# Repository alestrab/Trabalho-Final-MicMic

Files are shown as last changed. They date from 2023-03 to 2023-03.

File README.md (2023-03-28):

# Trabalho-Final-MicMic
Trabalho 7 da Disciplina de Microntroladores e Microprocessadores, Período 2022/2 - Engenharia Física - UFSCar;\
Grupo D, Professor da Disciplina: Dr. Ricardo Menotti
<div align="center">
 
Integrantes|RA
------|:----:
Alexandre Strabello|770076
Gabriel Lemes Molizane Almeida|770097
Sarah Brennda Bispo Almeida|770161

 <div align="left">
  
## Objetivos Gerais:
Girassol - Desenvolver um sistema para maximizar a intensidade luminosa em uma placa solar através da movimentação da mesma em dois eixos. 

### Objetivos Específicos:
Construir um suporte com um grau de liberdade em modelo 3D, com fácil adição de um segundo eixo de rotação;\
Desenvolvimento de um código para microcontrolador controlando dois servomotores em função da tensão de saída da placa solar;
 
## Materiais:

2 servomotores SG92R para controle dos eixos de rotação da placa solar; (por questão de disponibilidade foi utilizado um servomotor MG90S)

Mini Placa Solar ZW 110X69, tensão de operação 5 V, 1W;

Impressora 3D disponível no Espaço Maker do DC UFSCar;

Como microcontrolador foi utilizado um [Franzino](https://embarcados.com.br/franzino-open-hardware-de-baixo-custo/). O funcionamento do mesmo é o mesmo que um Arduino UNO, apenas necessita de uma placa externa para comunicação serial e não possui pinos de saída 3.3V.

## Plano de Trabalho

O projeto será separado com base nas quatro semanas disponíveis para sua realização;

### Primeira Semana:
Análise de viabilidade, quais componentes serão necessários, especificações sobre suas dimensões, assim como qual microcontrolador será utilizado;\
Também será construído uma primeira versão para controle de rotação em um único eixo em modelo 3D, onde será estudada a possibilidade de construção do mesmo em impressora 3D no laboratório maker do DC UFSCar;

### Segunda Semana:
Aperfeiçoamento do modelo e agendamento para impressão; \
Construção da segunda parte do modelo para controle no segundo eixo;\
Início do desenvolvimento do código para controle dos servomotores;

### Terceira Semana:
Impressão da segunda parte do suporte;\
Instalação e montagem do sistema da placa solar com os servomotores e demais componentes;\
Testes do código para controle e correções de bugs;

### Quarta Semana:
Correções de problemas;\
Elaboração de vídeo ou apresentação para a entrega final do projeto;

## Metodologia

Enquanto parte dos integrantes focam no desenvolvimento do suporte para fixação da placa e instalação dos servomotores, os outros membros serão responsáveis pela implementação do código para controle da rotação.

A inclinação da placa pode ser alterada em 45° para os dois lados, tal que será feito uma rotina para variar de 5° em 5° a inclinação enquanto faz a leitura da tensão na placa e verifica se houve redução ou não da mesma. Quando o movimento reduzir a intensidade luminosa, o mesmo irá parar de se movimentar nessa direção.

Em seguida, irá iniciar o movimento no segundo eixo, que pode rotacionar a placa em 360°, seguindo mesmo critério, movimentação em passo constante até identificar o pico de intensidade luminosa na placa.

## Realização do Plano de Trabalho

### Vídeo

O vídeo para apresentação do projeto Girassol e seu funcionamento está disponível no link: https://drive.google.com/file/d/1Eip5RgSgDWEnfYKRLRbnenWwQcjCiUuC/view?usp=share_link .

### Construção do modelo 3D

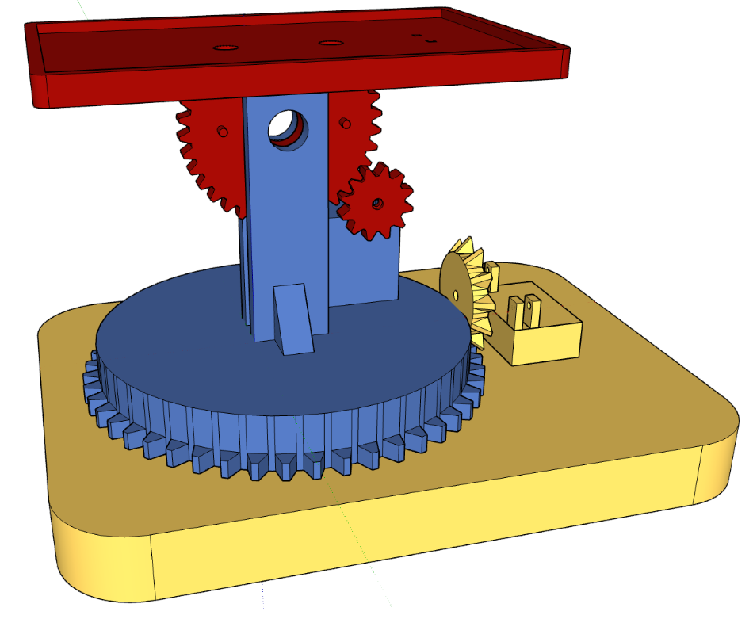
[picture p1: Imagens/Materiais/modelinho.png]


Utilizou-se o software Sketchup para construção dos suportes e sistemas para rotação da placa solar. O modelamento das engrenagens foi feito com base em objetos já existentes em um banco de projetos do aplicativo, enquanto o suporte foi pensado de acordo com alguns diagramas construidos inicialmente em papel. No total temos três grandes áreas, que seriam o controle de inclinação (em vermelho), o suporte para fixação da placa (em azul), além do suporte para o eixo de rotação (em amarelo).

Tanto o controle de inclinação quanto o suporte de fixação foram impressos em um laboratório do departamento de Física da universidade, contudo, por ordens dos responsáveis do local, não foi possível realizar a impressão do último componente. Verificou-se também que o eixo de rotação não poderia ser implementado utilizando um servomotor, tal como fora planejado.

O servomotor comprado apresenta limitação de rotação, podendo realizar no máximo um giro de 180°. Quando comparado com as engrenagens colocadas, a rotação máxima seria de 45°, muito inferior ao planejado de 360º. Como esse problema só foi identificado durante a implementação do controle de inclinação, não houve tempo para alteração do modelo, de modo que foi deixado de lado o controle de rotação.

### Montagem do aparato

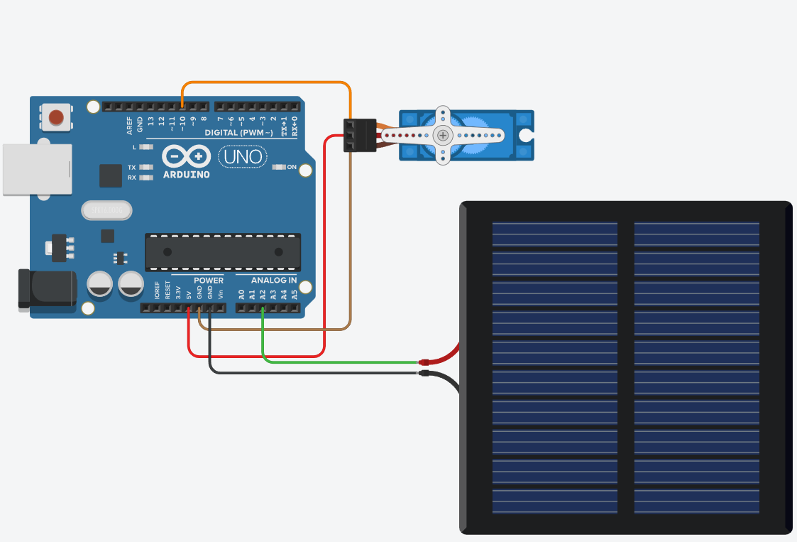
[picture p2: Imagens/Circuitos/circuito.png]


Os códigos escritos para o funcionamento do sistema necessitam que o cabo de sinal do servmotor esteja contectado no pino D10 do Franzino, enquanto o painel solar precisa estar no pino A2 do mesmo. Além disso, o servomotor deve ser ligado em 5 V, o que é feito através da mesma placa, utilizando os pinos de 5 V e GND; e o painel solar também deve ser aterrado na mesma placa. Essa, por sua vez, também deve ser alimentada por uma fonte de tensão contínua de 12 V.

Feito a impressão e o acabamento dos modelos 3D, deve-se acoplar a engrenagem chanfrada ao suporte do painel solar utilizando dois parafusos com 1,4 mm de raio. Em seguida, coloca-se a menor engrenagem no eixo do servomotor, parafusando se necessário, e encaixa-se esse motor na base.

Antes de acoplar a engrenagem do painel solar à engrenagem do servomotor, deve-se implementar o código do arquivo "teste_servo.cpp" no Franzino, com tudo devidamente conectado, como descrito anteriormente. Esse código tem como objetivo configurar o motor em sua posição de 90°. Feito isso, alinha-se o furo da engrenagem do painel com os furos do suporte, deixando a superfície plana do painel solar aproximadamente paralaela à base. Ao fazer isso, as engrenagens já irão se acoplar. Por fim, coloca-se o cilindro adequado passando pelos três furos. Assim, basta conectar o painel solar na placa como descrito anteriormente e implementar o código do arquivo "Girassol.cpp" para que o sistema funcione adequadamente.

### Funcionamento do sistema

<p align="center">
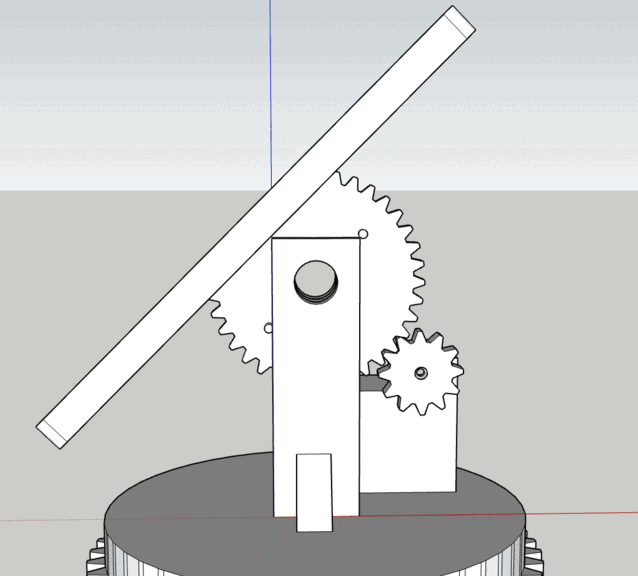
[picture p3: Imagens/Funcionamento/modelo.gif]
  
</p>

Primeiramente é importante ressaltar que a explicação que se segue é aquela utilizada para o sistema com apenas um eixo. O caso de dois eixos seria análogo, modificando como seriam pegos os pontos de iluminação, e tendo de controlar dois servomotores. 

A fim de fazer o painel solar se direcionar para o máximo de intensidade luminosa, utilizaram-se dois modos de funcionamento:

1. **Ajuste local**:
Nesse caso, dada uma posição inicial, o sistema procura o máximo local de intensidade. Para isso, comparam-se as intensidades luminosas em três pontos: o primeiro é aquele em que o sistema já se encontra, enquanto os outros dois são aqueles adjacentes a esse dado um passo, por exemplo de 5°. Comparando os três valores, o painel irá se direcionar para aquele com maior intensidade. Quando a posição de maior intensidade é a inicial, utiliza-se um atraso maior para a próxima análise. Esse modo de funcionamento, entretanto, só permite encontrar máximos locais.

2. **Scan**:
Para encontrar o máximo de intensidade geral é necessário fazer uma varredura de 0° a 180°, e é isso que esse modo faz. A rotina de scan só se ativa a cada intervalo de tempo, por exemplo 2 min. Nela, é feito um scan da intensidade luminosa no intervalo citado, e em seguida rotaciona-se o servomotor na posição do máximo.

Para a regulagem do intervalo de tempo entre as rotinas, utilizou-se a biblioteca disponível em https://github.com/khoih-prog/TimerInterrupt . Além disso, durante os testes observou-se um problema nas medidas do painel solar, apresentando ruídos consideráveis. Para lidar com isso, cada medição foi então substituída por um conjunto de 50 medições realizadas em intervalos de 1 ms, cuja média era definida como a medição desejada. Isso foi suficiente para evitar os ruídos encontrados e, portanto, foi implementado em ambos os modos de funcionamento.

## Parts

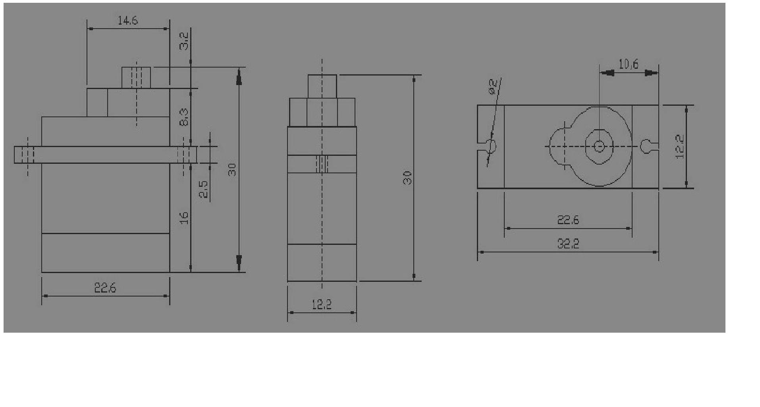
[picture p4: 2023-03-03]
Imagens/Materiais/Dimensões Servo.png

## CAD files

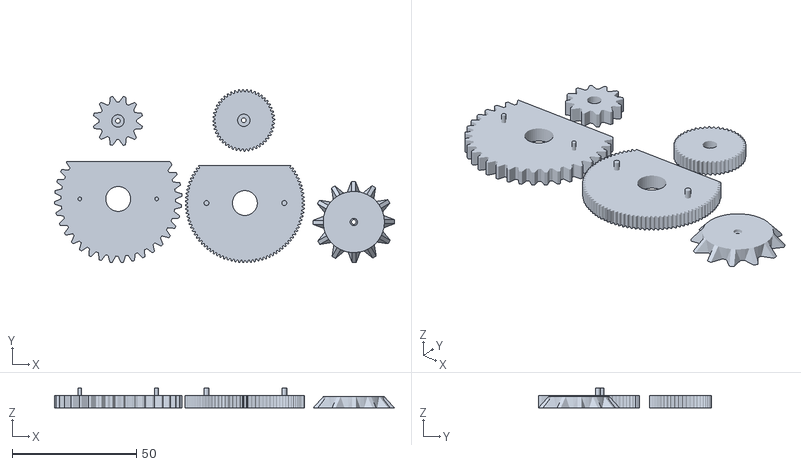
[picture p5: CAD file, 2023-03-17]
Modelos 3D/Arquivos para Impressão/Modelagem de Engrenagem.stl
136.6 x 69.7 x 8.00

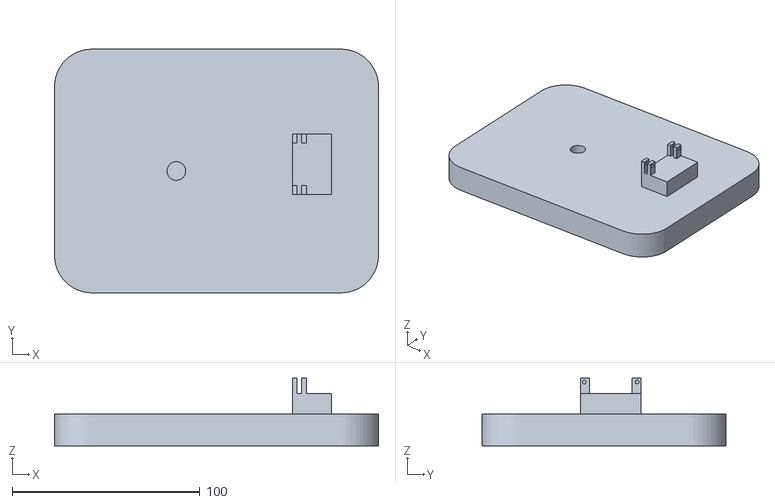
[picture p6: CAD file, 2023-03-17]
Modelos 3D/Arquivos para Impressão/base_segundoeixo.stl
172.8 x 130.0 x 36.0

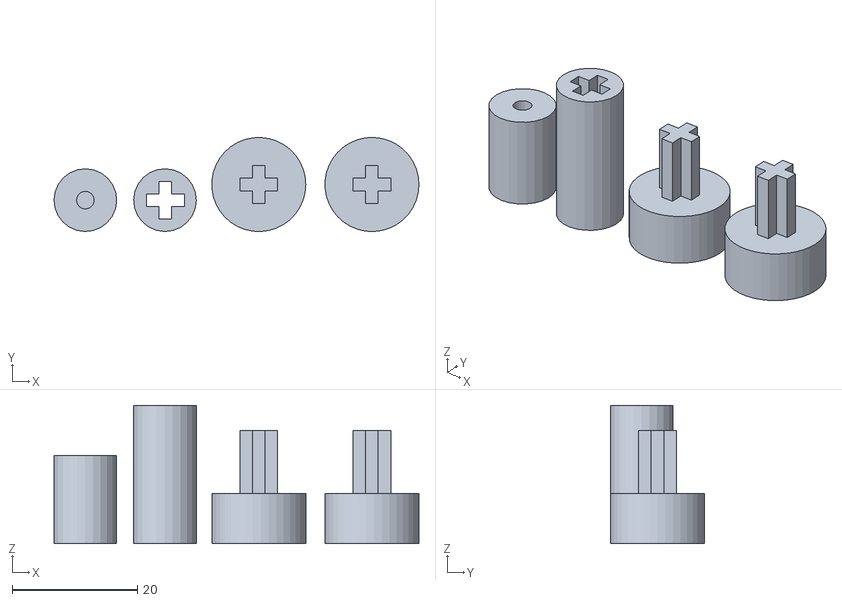
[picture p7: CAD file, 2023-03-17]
Modelos 3D/Arquivos para Impressão/cilindro fixacao painel.stl
58.2 x 15.0 x 22.0

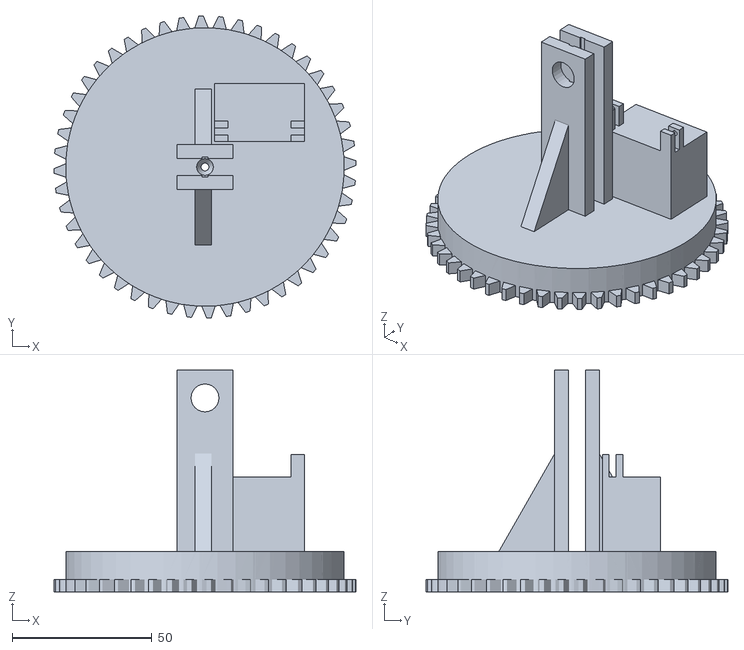
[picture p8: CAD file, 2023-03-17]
Modelos 3D/Arquivos para Impressão/suporte uni dim.stl
108.2 x 108.2 x 79.6

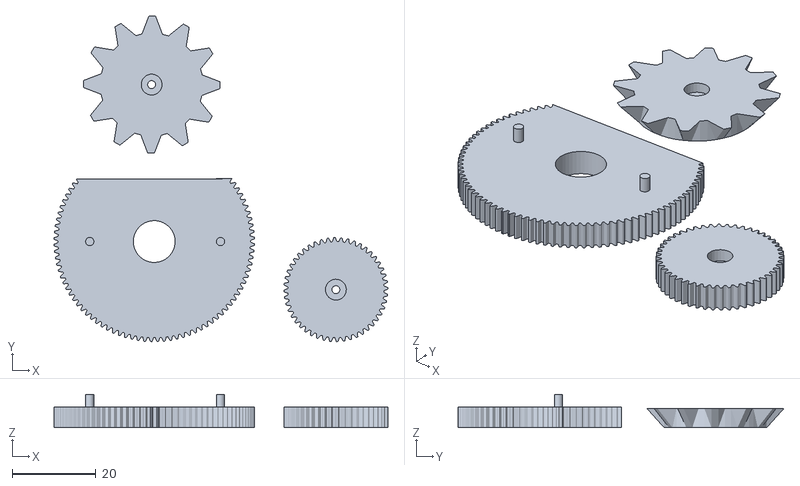
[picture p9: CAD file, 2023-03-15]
Modelos 3D/Arquivos para Impressão/Engrenagens.stl
79.9 x 77.9 x 8.00

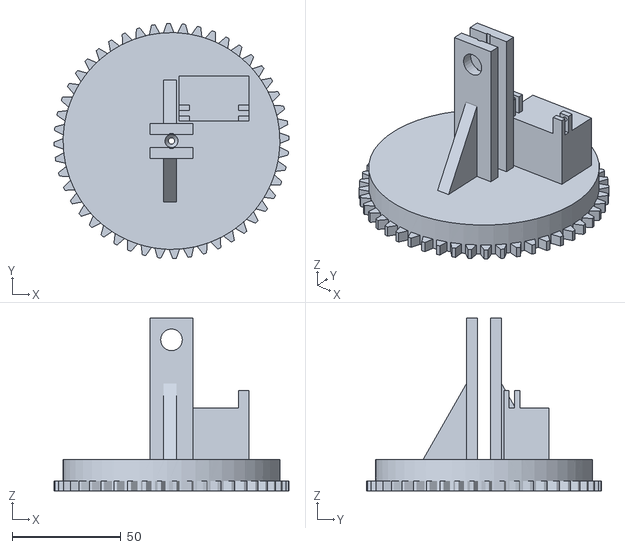
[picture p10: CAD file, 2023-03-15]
Modelos 3D/Arquivos para Impressão/base uni dim.stl
108.2 x 108.2 x 79.6

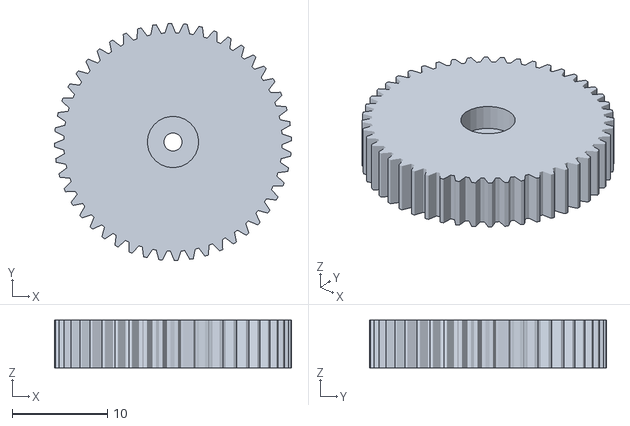
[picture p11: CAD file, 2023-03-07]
Modelos 3D/Arquivos para Impressão/Engrenagem_motor_painel.stl
24.9 x 24.9 x 5.00

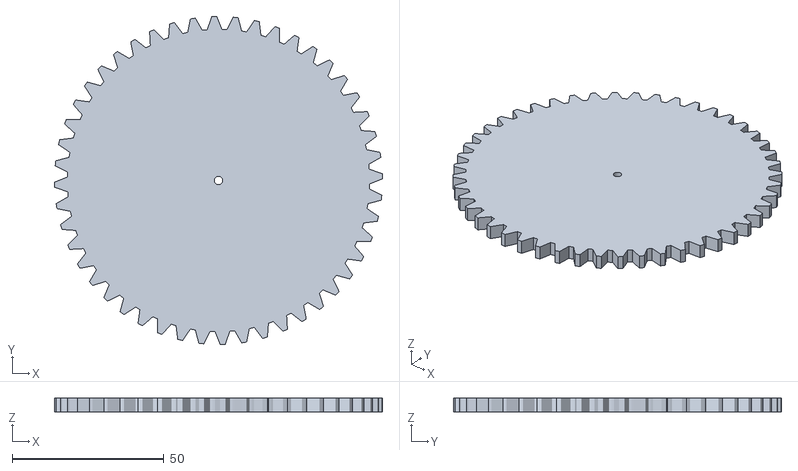
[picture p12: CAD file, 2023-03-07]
Modelos 3D/Arquivos para Impressão/Engrenagem_base_chanfrada.stl
108.2 x 108.2 x 4.55

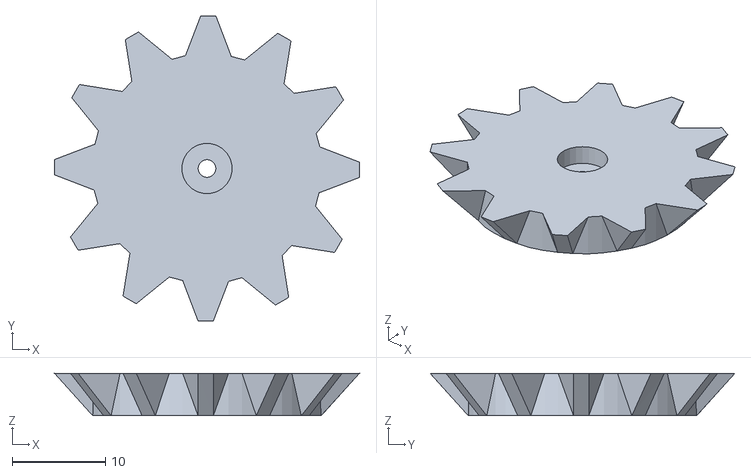
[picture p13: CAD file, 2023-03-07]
Modelos 3D/Arquivos para Impressão/Engrenagem_eixo_chanfrada.stl
32.7 x 32.7 x 4.55

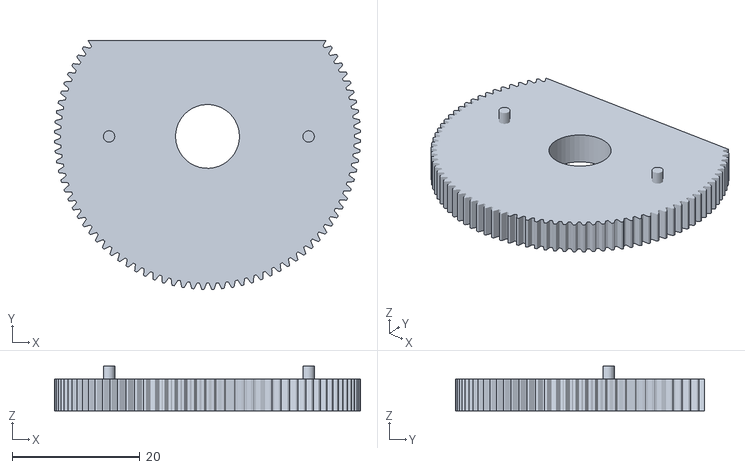
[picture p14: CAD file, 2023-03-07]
Modelos 3D/Arquivos para Impressão/Engrenagem_base_painel.stl
47.9 x 39.0 x 7.00

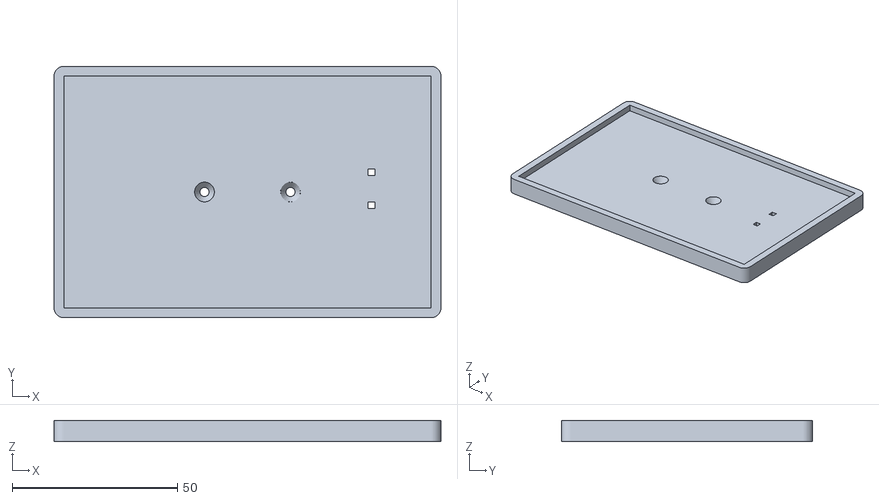
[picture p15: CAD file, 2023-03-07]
Modelos 3D/Arquivos para Impressão/Base Painel.stl
117.0 x 76.0 x 6.50

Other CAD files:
Modelos 3D/Base Motor.skp
Modelos 3D/Base Painel.skp
Modelos 3D/Modelagem de Engrenagem.skp
Modelos 3D/Retangulo de Suporte.skp
Modelos 3D/base_segundoeixo.skp
Modelos 3D/cilindro fixacao painel.skp
Modelos 3D/modelo_segundoeixo.skp
Modelos 3D/modelo_uni_mk1.skp
Modelos 3D/modelo_uni_mk2.skp
Modelos 3D/modelo_uni_mk3.skp
Modelos 3D/suporte uni dim.skp

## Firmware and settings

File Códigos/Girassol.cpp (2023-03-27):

#include <Arduino.h>
#include <Servo.h>
//Código final para o funcionamento do projeto Girassol

#define TIMER_INTERRUPT_DEBUG         2
#define _TIMERINTERRUPT_LOGLEVEL_     0

#define USE_TIMER_1     false   //Timer utilizado na biblioteca do servomotor
#define USE_TIMER_2     true    //Timer utilizado para interrupção neste programa

#include "TimerInterrupt.h"

int passo = 5;                //passo para scan
int servo = 0;                //graus do servomotor
unsigned int sol0 = 0;        //iluminação na posição atual
unsigned int sol1 = 0;        //iluminação na posição incrementada
unsigned int sol2 = 0;        //iluminação na posição decrementada
int servo0 = 0;               //posição inicial do servo
unsigned int sol[180];        //iluminação em cada posicao
int solmax = 0;               //iluminação máxima
int dif = 0;                  //diferença entre iluminações
byte maxIndex = 0;            //índice da maior iluminação
Servo servo_10;               //servomotor
int aux = 0;                  //variável auxiliar utilizada para alternar entre os modos de scan e ajuste local
int N = 50;

#if !defined(LED_BUILTIN)      //LED do arduino
  #define LED_BUILTIN     13
#endif

////////////////////////////////////////////////////////////////
#if USE_TIMER_2
void TimerHandler(unsigned int outputPin1 = LED_BUILTIN)
{
  static bool toggle = false;

#if (TIMER_INTERRUPT_DEBUG > 1)
  Serial.print("ITimer2 called, millis() = ");
  Serial.println(millis());
#endif

  digitalWrite(outputPin1, toggle); //Escreve o valor de toggle no LED da placa
  aux = !aux;                       //Troca o valor da variável auxiliar entre 0 e 1
  toggle = !toggle;                 //Troca o valor de toggle entre 0 e 1

 }
#endif
///////////////////////////////////////////////////////////////////

unsigned int outputPin1 = LED_BUILTIN;

#define TIMER_INTERVAL_MS     120000  //Intervalo de tempo em ms em que o sistema fará o scan
#define TIMER_FREQUENCY       (float) (1000.0f / TIMER_INTERVAL_MS)

#define TIMER1_DURATION_MS    0
#define TIMER_DURATION_MS     0


void setup()
{ 
  servo_10.attach(10, 500, 2500);       //Associa o servomotor ao pino 10
  pinMode(A2, INPUT);                   //Pino A2 referente à saída do painel solar
  pinMode(outputPin1, OUTPUT);          //LED da placa como output
  servo_10.write(90);                   //Configuração inicial do servomotor em 90°, que deve corresponder à posição horizontal
  
  Serial.begin(9600);
  while (!Serial);

  Serial.print(F("\nStarting TimerInterruptTest on "));
  Serial.println(BOARD_TYPE);
  Serial.println(TIMER_INTERRUPT_VERSION);
  Serial.print(F("CPU Frequency = ")); Serial.print(F_CPU / 1000000); Serial.println(F(" MHz"));

///////////////////////////////////////////////////////////////////
#if USE_TIMER_2 
  ITimer2.init();
  if (ITimer2.attachInterruptInterval(TIMER_INTERVAL_MS, TimerHandler, outputPin1, TIMER_DURATION_MS))
  {
    Serial.print(F("Starting  ITimer2 OK, millis() = ")); Serial.println(millis());
  }
  else
    Serial.println(F("Can't set ITimer2. Select another freq. or timer"));
    
#endif
}
///////////////////////////////////////////////////////////////////

void loop()
{
  //AJUSTE LOCAL
  //Executado em loop quando aux = 0
  //As medições de sol0, sol1 e sol2 foram feitas tomando-se a média de 50 medições consecutivas em intervalos e 1ms
  if ((aux == 0)){
  servo = servo_10.read();
  //Leitura de sol0
  for (byte i = 0; i < N; i++)
      {
        sol0 = sol0 + analogRead(A2);
        delay(1);
      }
      sol0 = sol0/N;

  //Caso fora das bordas
  if ((servo>=passo)&(servo<=180-passo)){
      //Posição incrementada
      servo_10.write(servo+passo);
      delay(50);
      //Leitura de sol1
      for (byte i = 0; i < N; i++)
      {
        sol1 = sol1 + analogRead(A2);
        delay(1);
      }
      sol1 = sol1/N;

      //Posição decrementada
      servo_10.write(servo-passo);
      delay(50);
      //Leitura de sol2
      for (byte i = 0; i < N; i++)
      {
        sol2 = sol2 + analogRead(A2);
        delay(1);
      }
      sol2 = sol2/N;

      //Movimentação do servomotor para a posição de maior intensidade entre sol0, sol1 e sol2
      if (sol1>max(sol0,sol2)){
        servo_10.write(servo+passo);
      }
      if (sol0>=max(sol1,sol2)){
        servo_10.write(servo);
        delay(1000);  //Delay maior quando o servomotor se mantém na mesma posição
      }
      if (sol2>max(sol0,sol1)){
        servo_10.write(servo-passo);
      }
    }

    //Caso próximo do limite inferior
    if (servo<passo){
      //Posição incrementada
      servo_10.write(servo+passo);
      delay(50);
      //Leitura de sol1
      for (byte i = 0; i < N; i++)
      {
        sol1 = sol1 + analogRead(A2);
        delay(1);
      }
      sol1 = sol1/N;

      //Movimentação do servomotor para a posição de maior intensidade entre sol0 e sol1
      if (sol1>sol0){
        servo_10.write(servo+passo);
      }
      if (sol0>=sol1){
        servo_10.write(servo);
        delay(1000);  //Delay maior quando o servomotor se mantém na mesma posição
      }
    }

    //Caso próximo do limite superior
    if (servo>180-passo){
      servo_10.write(servo-passo);
      delay(50);
      //Leitura de sol2
      for (byte i = 0; i < N; i++)
      {
        sol2 = sol2 + analogRead(A2);
        delay(1);
      }
      sol2 = sol2/N;

      //Movimentação do servomotor para a posição de maior intensidade entre sol0 e sol2
      if (sol2>sol0){
        servo_10.write(servo-passo);
      }
      if (sol0>=sol2){
        servo_10.write(servo);
        delay(1000); //Delay maior quando o servomotor se mantém na mesma posição
      }
    }
    servo = servo_10.read();
      Serial.print(F("sol0 = "));Serial.print(sol0);
      Serial.print(F("  sol1 = "));Serial.print(sol1);
      Serial.print(F("  sol2 = "));Serial.println(sol2);
      Serial.print(F("Servo = "));Serial.println(servo);
    delay(500);
  }


  //SCAN
  //Executado uma vez quando aux = 1
  //As medições de sol[] também foram feitas tomando-se a média de 50 medições consecutivas em intervalos e 1ms
  if ((aux == 1)){
    servo_10.write(0);
    servo = servo_10.read();
    delay(500);
    //Leitura de sol[0]
    for (byte i = 0; i < N; i++)
      {
        sol[servo] = sol[servo] + analogRead(A2);
        delay(1);
      }
      sol[servo] = sol[servo]/N;
    
    //Varredura e leitura dos demais valores de intensidade luminosa
    do
    {
      servo_10.write(servo+1);
      delay(20);
      servo = servo_10.read();
      for (byte i = 0; i < N; i++)
      {
        sol[servo] = sol[servo] + analogRead(A2);
        delay(1);
      }
      sol[servo] = sol[servo]/N;
      
      

      Serial.print(F("servo = "));Serial.print(servo);Serial.print(F("      sol = "));Serial.println(sol[servo]);
    } while (servo<180);

    //Determinação de solmax, a iluminação máxima, junto com o ângulo de rotação do servomotor dessa medição
    solmax = sol[0];
    for(byte i = 1; i < 180; i++)
    {
        if(sol[i] > solmax) {
            solmax = sol[i];
            maxIndex = i;
        }
    }
    servo_10.write(maxIndex);
    Serial.println(maxIndex);
    Serial.println(solmax);
    aux = !aux;  //Faz aux = 0, retornando ao modo de ajuste local até a próxima interrupção
    delay(1000);
  }
  
}

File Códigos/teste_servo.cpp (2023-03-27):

#include <Arduino.h>
#include <Servo.h>
//Teste do servomotor
int servo = 0;  //Valor de ângulo do servo em graus

Servo servo_10; //Definição do servomotor

void setup()
{
  servo_10.attach(10, 500, 2500); //Servomotor conectado ao pino D10
  Serial.begin(9600);
}

void loop()
{
  servo = servo_10.read();
  Serial.println(servo);
  servo_10.write(90); //Coloca o servomotor na posição de 90°
  delay(1000);
}

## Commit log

2023-03-02 Primeira Versão - Unidimensional
    [modelo_uni_mk1.skp]
2023-03-03 Separação do suporte em componentes
    [Engrenagem Motor.skp, Engrenagem Suporte.skp, Retangulo de Suporte.skp]
2023-03-03 Update README.md
    Adicionada lista de materiais
2023-03-03 Detalhamento do suporte de placa e locais para fixação
    [Base Painel.skp, Engrenagem Suporte.skp, modelo_uni_mk1.skp]
2023-03-03 Detalhamento do suporte para base do servo
    [Base Motor.skp, Base Painel.skp, Engrenagem Motor.skp]
2023-03-04 Aprimoramento e Adição do Segundo Eixo de Rotação
    [Engrenagem Motor.skp, Modelagem de Engrenagem.skp, base.skp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]
2023-03-07 Exportação dos Modelos 3D
    [Base Painel.stl, Engrenagem_base_chanfrada.stl, Engrenagem_base_painel.stl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]
2023-03-07 Update README.md
    Explicação do código que será desenvolvido e correção da formatação
2023-03-14 Add files via upload
    Testes para o motor e para o painel solar separadamente. O teste do painel funcionou, entretanto o do motor não.
2023-03-15 finalização dos modelos 3D
    [Modelagem de Engrenagem.skp, base uni dim.stl, base_segundoeixo.skp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]
2023-03-15 Correção Engrenagens
    [Engrenagens.stl, Modelagem de Engrenagem.skp]
2023-03-17 Alteração dos Dentes de Engrenagens
    [Modelagem de Engrenagem.skp, Modelagem de Engrenagem.stl, base_segundoeixo.skp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]
2023-03-18 Códigos Iniciais
    Código para teste dos componentes
2023-03-27 Adição de Imagem do Modelo 3D
2023-03-27 Retira de Arquivos Temporários
    [Engrenagem Motor.skp, Engrenagem Suporte.skp, base.skp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]
2023-03-27 Conexões para o circuito
2023-03-27 Ilustração do Circuito
